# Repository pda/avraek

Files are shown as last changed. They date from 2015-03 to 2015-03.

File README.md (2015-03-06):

ADB Apple Desktop Bus keyboard adapter
======================================

Aims to use a cheap microcontroller to expose an Apple Extended Keyboard II
as a USB keyboard.

Hardware
--------

Single ADB data line connects to bottom-left pin of keyboard Mini-DIN with 1K pull-up resistor.

ATtiny328p (Arduino Uno)
------------------------

Defaults ADB to `PORTB` bit `0` which is ATmega328p pin 14, and Arduino digital
pin 8. See `Makefile` to override this using environment variables.

```sh
make clean all burn
```

ATtiny85
--------

Set to internal 16.5 MHz frequency like http://www.obdev.at/products/vusb/easylogger.html

```
# Fuse high byte:
# 0xdd = 1 1 0 1   1 1 0 1
#        ^ ^ ^ ^   ^ \-+-/ 
#        | | | |   |   +------ BODLEVEL 2..0 (brownout trigger level -> 2.7V)
#        | | | |   +---------- EESAVE (preserve EEPROM on Chip Erase -> not preserved)
#        | | | +-------------- WDTON (watchdog timer always on -> disable)
#        | | +---------------- SPIEN (enable serial programming -> enabled)
#        | +------------------ DWEN (debug wire enable)
#        +-------------------- RSTDISBL (disable external reset -> enabled)
#
# Fuse low byte:
# 0xe1 = 1 1 1 0   0 0 0 1
#        ^ ^ \+/   \--+--/
#        | |  |       +------- CKSEL 3..0 (clock selection -> HF PLL)
#        | |  +--------------- SUT 1..0 (BOD enabled, fast rising power)
#        | +------------------ CKOUT (clock output on CKOUT pin -> disabled)
#        +-------------------- CKDIV8 (divide clock by 8 -> don't divide)
```

```sh
avrdude -p attiny85 -c usbtiny -U hfuse:w:0xdd:m -U lfuse:w:0xe1:m
```

Build the code, use `PORTB` bit `3` which is ATtiny85 pin 2:

```sh
MCU=attiny85 F_CPU=16500000 ISP_PROGRAMMER=usbtiny ADB_PORT_BIT=3 make clean all burn
```

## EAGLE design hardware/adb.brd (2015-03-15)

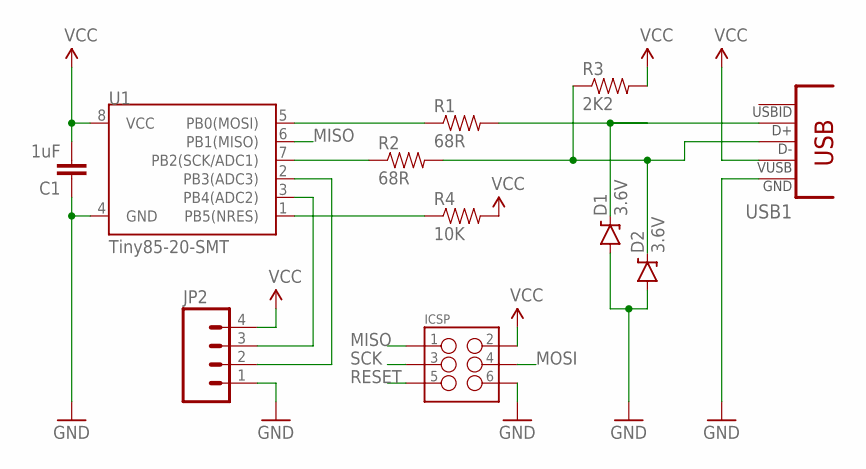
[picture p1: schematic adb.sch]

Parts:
C1: 1uF; 0805
D1, D2: 3.6V; SOD-323
ICSP: M03X22X3_SILK_SM; 2X3
JP2: M04PTH; 1X04
R1, R2: 68R; 0805
R3: 2K2; 0805
R4: 10K; 0805
U1: Tiny85-20-SMT; SO08-EIAJ
USB1: CON-USB-F-MICRO-B; CONN_USB_MICRO-B

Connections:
D+: D1.C, R1.2, USB1.P3 (D+)
D-: D2.C, R2.2, R3.1, USB1.P2 (D-)
GND: C1.1, D1.A, D2.A, ICSP.6, JP2.1, U1.4 (GND), USB1.P5 (GND)
MISO: ICSP.1, U1.6 (PB1(MISO))
MOSI: ICSP.4, R1.1, U1.5 (PB0(MOSI))
PB3: JP2.2, U1.2 (PB3(ADC3))
PB4: JP2.3, U1.3 (PB4(ADC2))
RESET: ICSP.5, R4.1, U1.1 (PB5(NRES))
SCK: ICSP.3, R2.1, U1.7 (PB2(SCK/ADC1))
VCC: C1.2, ICSP.2, JP2.4, R3.2, R4.2, U1.8 (VCC), USB1.P1 (VUSB)

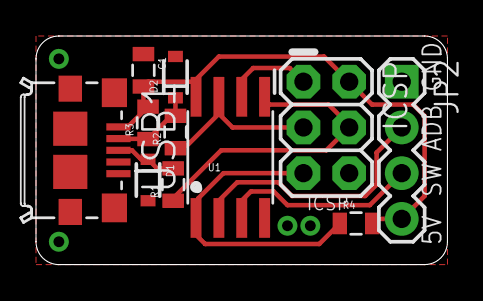
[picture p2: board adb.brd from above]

Board: 2 copper layers, 22.9 x 12.7 mm, 11 parts (0 on the bottom side), 10 nets.

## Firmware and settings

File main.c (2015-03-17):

#include "adb.h"
#include "adb_keyboard.h"
#include "aek2_keys.h"
#include "keybuffer.h"
#include "usb_keyboard.h"
#include "keymap.h"

#include <avr/interrupt.h>
#include <avr/io.h>
#include <stdint.h>

static void poll_adb();
static void handle_keyboard_transition(uint8_t t);

int main() {
  usb_keyboard_init();
  adb_keyboard_initialize();
  sei();
  while (1) {
    poll_adb();
    usb_keyboard_poll();
  }
}

static void poll_adb() {
  struct adb_response_16 response;
  adb_keyboard_poll(&response);
  if (!response.timed_out) {
    handle_keyboard_transition(response.a);
    handle_keyboard_transition(response.b);
    usb_keyboard_interrupt_with_keyboard_report();
  }
}

static void handle_keyboard_transition(uint8_t t) {
  if (t == 0xFF) return;
  uint8_t isUp = t >> 7;
  uint8_t key_adb = t & 0x7F;
  uint8_t key_usb = aek2_keymap[key_adb];
  if (isUp) {
    switch (key_adb) {
      case ADB_KEY_CTRL:
        keyboard_report.modifier &= ~_BV(0);
        break;
      case ADB_KEY_SHIFT:
        keyboard_report.modifier &= ~_BV(1);
        break;
      case ADB_KEY_OPTION:
        keyboard_report.modifier &= ~_BV(2);
        break;
      case ADB_KEY_CMD:
        keyboard_report.modifier &= ~_BV(3);
        break;
      default:
        keybuffer_up(&keybuffer, key_usb);
        break;
    }
  } else {
    switch (key_adb) {
      case ADB_KEY_CTRL:
        keyboard_report.modifier |= _BV(0);
        break;
      case ADB_KEY_SHIFT:
        keyboard_report.modifier |= _BV(1);
        break;
      case ADB_KEY_OPTION:
        keyboard_report.modifier |= _BV(2);
        break;
      case ADB_KEY_CMD:
        keyboard_report.modifier |= _BV(3);
        break;
      default:
        keybuffer_down(&keybuffer, key_usb);
        break;
    }
  }
}

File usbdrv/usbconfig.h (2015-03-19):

/* Name: usbconfig.h
 * Project: V-USB, virtual USB port for Atmel's(r) AVR(r) microcontrollers
 * Author: Christian Starkjohann
 * Creation Date: 2005-04-01
 * Tabsize: 4
 * Copyright: (c) 2005 by OBJECTIVE DEVELOPMENT Software GmbH
 * License: GNU GPL v2 (see License.txt), GNU GPL v3 or proprietary (CommercialLicense.txt)
 */

#ifndef __usbconfig_h_included__
#define __usbconfig_h_included__

/*
General Description:
This file is an example configuration (with inline documentation) for the USB
driver. It configures V-USB for USB D+ connected to Port D bit 2 (which is
also hardware interrupt 0 on many devices) and USB D- to Port D bit 4. You may
wire the lines to any other port, as long as D+ is also wired to INT0 (or any
other hardware interrupt, as long as it is the highest level interrupt, see
section at the end of this file).
+ To create your own usbconfig.h file, copy this file to your project's
+ firmware source directory) and rename it to "usbconfig.h".
+ Then edit it accordingly.
*/

/* ---------------------------- Hardware Config ---------------------------- */

#define USB_CFG_IOPORTNAME      B
/* This is the port where the USB bus is connected. When you configure it to
 * "B", the registers PORTB, PINB and DDRB will be used.
 */
#define USB_CFG_DMINUS_BIT      2
/* This is the bit number in USB_CFG_IOPORT where the USB D- line is connected.
 * This may be any bit in the port.
 */
#define USB_CFG_DPLUS_BIT       0
/* This is the bit number in USB_CFG_IOPORT where the USB D+ line is connected.
 * This may be any bit in the port. Please note that D+ must also be connected
 * to interrupt pin INT0! [You can also use other interrupts, see section
 * "Optional MCU Description" below, or you can connect D- to the interrupt, as
 * it is required if you use the USB_COUNT_SOF feature. If you use D- for the
 * interrupt, the USB interrupt will also be triggered at Start-Of-Frame
 * markers every millisecond.]
 */
#define USB_CFG_CLOCK_KHZ       (F_CPU/1000)
/* Clock rate of the AVR in kHz. Legal values are 12000, 12800, 15000, 16000,
 * 16500, 18000 and 20000. The 12.8 MHz and 16.5 MHz versions of the code
 * require no crystal, they tolerate +/- 1% deviation from the nominal
 * frequency. All other rates require a precision of 2000 ppm and thus a
 * crystal!
 * Since F_CPU should be defined to your actual clock rate anyway, you should
 * not need to modify this setting.
 */
#define USB_CFG_CHECK_CRC       0
/* Define this to 1 if you want that the driver checks integrity of incoming
 * data packets (CRC checks). CRC checks cost quite a bit of code size and are
 * currently only available for 18 MHz crystal clock. You must choose
 * USB_CFG_CLOCK_KHZ = 18000 if you enable this option.
 */

/* ----------------------- Optional Hardware Config ------------------------ */

/* #define USB_CFG_PULLUP_IOPORTNAME   B */
/* If you connect the 1.5k pullup resistor from D- to a port pin instead of
 * V+, you can connect and disconnect the device from firmware by calling
 * the macros usbDeviceConnect() and usbDeviceDisconnect() (see usbdrv.h).
 * This constant defines the port on which the pullup resistor is connected.
 */
/* #define USB_CFG_PULLUP_BIT          1 */
/* This constant defines the bit number in USB_CFG_PULLUP_IOPORT (defined
 * above) where the 1.5k pullup resistor is connected. See description
 * above for details.
 */

/* --------------------------- Functional Range ---------------------------- */
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

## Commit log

2015-03-01 main.c: send 3ms reset pulse to ADB bus.
    [main.c]
2015-03-01 PORTB, DDRB and pin 0 refs moved from adb.{c,h} to Makefile.
2015-03-01 avr-uart submodule.
2015-03-01 avr-uart integrated; status output.
2015-03-02 main.c: stream stdout to uart0 for printf.
2015-03-02 Animate keyboard LEDs on start-up.
2015-03-02 adb_reset: wait 100ms + 200ms during reset.
    Otherwise some resets, especially during power-up, are unsuccessful.
    [adb.c, main.c]
2015-03-02 Remove unused uart printf()
2015-03-04 Raw key codes (register 0) logged to UART0 every 500ms.
2015-03-04 print key transitions to UART0 e.g. "up: 1F (31)"
2015-03-06 UART / printf support deleted; attiny85 incompatible.
    [main.c]
2015-03-06 README.md with some hardware/build/fuse notes.
2015-03-15 hardware: adb.brd and adb.sch; work in progress.
    [adb.brd, adb.sch]
2015-03-15 hardware: bumped ICSP up, rearranged Rs and Ds.
    [adb.brd]
2015-03-15 hardware: AVR reset pulled high.
    [adb.brd, adb.sch]
2015-03-15 hardware: tweaks; Eagle 7.2 upgrade.
    [adb.brd]
2015-03-15 hardware: polish; silk screen text etc.
    [adb.brd, adb.sch]
2015-03-15 hardware: rounded corners; silk tweaks.
    [adb.brd]
2015-03-15 hardware: DRU from SparkFun not OSHPark
    [adb.brd]
2015-03-15 usbdrv vendored; HID descriptor; appears on USB host.
    * Successfully appears on the host computer USB device list.
    * Uses PB1 to connect/disconnect USB via D- pull-up resistor.
    * Not currently on schematic.
    * Will attempt to do away with this.
2015-03-15 hardware/.gitignore: ignore gerbers produced by OSHPark CAM.
2015-03-15 Gerbv (Gerber Viewer) project file.
2015-03-15 usbconfig.h: disable USB_CFG_PULLUP; pull-up hard-wired to VCC.
2015-03-15 usbconfig.h: USB_CFG_MAX_BUS_POWER 200 mA
2015-03-15 WIP: ADB key presses send USB key presses, but all wrong.
    [main.c, usbconfig.h]
2015-03-17 usbSetInterrupt() once per ADB response, not per transition.
    ADB responses contain one or two transitions, but there's no point
    setting USB interrupt for each of them.
2015-03-17 adb.c open-drain; pulls low, releases to hi-Z for high.
    ADB circuit includes external pull-up resistor.
2015-03-19 Calibrate oscillator using V-USB osccal code.
    [usbconfig.h]

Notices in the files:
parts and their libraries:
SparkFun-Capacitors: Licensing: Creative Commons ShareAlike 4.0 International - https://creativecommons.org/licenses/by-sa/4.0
